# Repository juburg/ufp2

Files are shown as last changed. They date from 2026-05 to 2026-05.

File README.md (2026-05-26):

# UFP2 Firmware

Locked rebuild repository for the UFP-II firmware.

The current production build is:

```text
UFP2_V160/UFP2_V160.ino
```

The source was recovered from:

```text
C:\Users\juerg\Documents\_onedrive_kopie\Desktop\SW\UFP2_V160.ino
```

That file is the V1.60 production source from 2021-11-15. The code still reports
`SWversion = 1.51` on the display. This is preserved as-is because the goal here is
to rebuild the known production binary, not to polish the archaeology.

## Build

Use Arduino CLI:

```powershell
.\tools\build-ufp2.ps1
```

## Firmware Export

To create firmware files for external flashing:

```powershell
.\tools\export-ufp2-firmware.ps1 -SkipCoreInstall
```

If PowerShell script execution is blocked:

```cmd
tools\export-ufp2-firmware.bat -SkipCoreInstall
```

The exported files are written to `dist/UFP2_V160/` as `.bin`, `.hex`, and `.uf2`.
The `.uf2` file targets the Adafruit Feather M0/SAMD21 application start address
`0x2000` and can be copied to a Feather M0 UF2 bootloader drive if that bootloader
is installed.

The script installs and uses `adafruit:samd@1.7.17` in a workspace-local Arduino CLI
data directory and compiles only against the vendored third-party libraries in this
repository.

## Target

```text
Board: Adafruit Feather M0
FQBN:  adafruit:samd:adafruit_feather_m0:opt=small,usbstack=arduino,debug=off
```

## Mechanical Files

The latest UFP2 enclosure STL files are archived under:

```text
UFP_latest/UFP_latest/
```

## Historical Compiler Log

The original Arduino IDE 1.8.19 compiler log is archived at:

```text
docs/arduino-ide-1.8.19-build.log
```

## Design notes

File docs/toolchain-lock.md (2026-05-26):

# Toolchain Lock for UFP2

This repository contains the locked Arduino CLI rebuild path for UFP-II firmware:

```text
UFP2_V160/UFP2_V160.ino
```

## Pinned Build Inputs

- Board package: `adafruit:samd@1.7.17`
- Board package index: `https://adafruit.github.io/arduino-board-index/package_adafruit_index.json`
- FQBN: `adafruit:samd:adafruit_feather_m0:opt=small,usbstack=arduino,debug=off`
- Board: Adafruit Feather M0, SAMD21G18A / Cortex-M0+

The build script uses a workspace-local Arduino CLI data directory under:

```text
../.arduino-cli-ufp2
```

This prevents the compile from silently using libraries from the user's Arduino
sketchbook. Silence is nice in churches, less so in firmware builds.

## Vendored Arduino Libraries

The script builds only with these repository-local libraries:

```text
third_party/arduino-libraries/RadioHead-1.112
third_party/arduino-libraries/U8g2-2.31.2
third_party/arduino-libraries/DimmerZero-1.0.0
```

Core libraries are supplied by `adafruit:samd@1.7.17`:

```text
Wire 1.0
SPI 1.0
Adafruit_ZeroDMA 1.1.3
```

## Build Command

```powershell
.\tools\build-ufp2.ps1
```

## Firmware Export

```powershell
.\tools\export-ufp2-firmware.ps1 -SkipCoreInstall
```

The batch wrapper avoids PowerShell execution policy issues:

```cmd
tools\export-ufp2-firmware.bat -SkipCoreInstall
```

The export creates `dist/UFP2_V160/UFP2_V160.bin`,
`dist/UFP2_V160/UFP2_V160.hex`, and `dist/UFP2_V160/UFP2_V160.uf2`.
The UF2 file uses SAMD21 family ID `0x68ED2B88` and target address `0x2000`,
matching the Feather M0 linker script with the 8 KB bootloader region.

## Verified Output

Fresh local build with the repository-local Arduino CLI path:

```text
UFP2_V160 / V1.6.0:
Sketch uses 53008 bytes (20%) of program storage space. Maximum is 262144 bytes.
```

The archived Arduino IDE 1.8.19 compiler log reported 52984 bytes. The CLI build is
24 bytes larger, matching the same small delta seen on the related UFP2_RRC rebuild.

## Offline Boundary

The third-party Arduino libraries are vendored in this repository.
The Adafruit SAMD core and ARM toolchain are installed by Arduino CLI from the
Adafruit and Arduino package indexes when the script is run without
`-SkipCoreInstall`.

For a fully offline rebuild, archive the workspace-local
`../.arduino-cli-ufp2/data/packages` directory separately.

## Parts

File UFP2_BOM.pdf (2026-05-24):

Bill of Materials | UFP-II
Source Data From: | UFP2.PrjPcb
Project: | UFP2.PrjPcb
Variant: | None
Creation Date: | 12.10.2018 15:22:01
Print Date: | 03-Nov-18 3:59:32 PM
Coding & Comments | Quantity | Comment | Description | Designator
105 | 7 | 1uF | Capacitor THT 5.08 | C1, C2, C4, C6, C8, C10, C15
102 | 1 | 1nF 50V | Capacitor THT 5.08 | C3
473 | 3 | 47n 50V | Capacitor THT 5.08 | C5, C7, C9
334 | 3 | 330n | Capacitor THT 5.08 | C12, C13, C14
watch orientation! | 1 | 1N4148 | Diode, 200 mA, 100 V, 2-Pin DO-35 | D1
| 1 | Header 16 | Header, 16-Pin | JP1
| 1 | Header 12 | Header, 12-Pin | JP2
watch orientation! | 1 | SIL03-1A72-71D | RELAY REED SPST 0.5A 3V 500Ohm | K1
| 2 | Header 4x3 | Servo-Header | P1, P6
| 2 | Header 4 | Header, 4-Pin | P2, P3
| 1 | Header 3x3 | Servo-Header | P4
do not populate | 1 | JST_ZH_5 | Optional connector | P5
| 1 | Header 3X2 | Header, 3-Pin, Dual row | P7
watch orientation! | 2 | BC547BG | 'NPNTransistor , 3-Pin TO-92 | Q1, Q2
brown-black-green | 4 | 1M | Resistor 125mW 5% | R1, R8, R15, R21
yellow-violett-red | 1 | 4k7 | Resistor 125mW 5% | R2
brown-black-orange | 5 | 10k | Resistor 125mW 5% | R3, R5, R12, R17, R24
orange-orange-brown | 3 | 330R | 'Resistor 125mW 5% | R4, R6, R7
orange-orange-red | 3 | 3k3 | 'Resistor 125mW 5% | R18, R19, R26
brown-black-red | 10 | 1k | 'Resistor 125mW 5% | R9, R10, R11, R14, R16, R22, R23, R27, R28, R29
brown-black-yellow | 3 | 100k | 'Resistor 125mW 5% | R13, R20, R25
watch orientation! | 1 | KPM-G1240A | KPM-G1240A-K6390 Piezo sound generator | SG1
watch orientation! | 1 | LM339N | Quad Comparator, 14-pin MDIP | U1
| 58
Approved | | Notes
Altium Limited Confidential | 03.11.2018 | Page 1

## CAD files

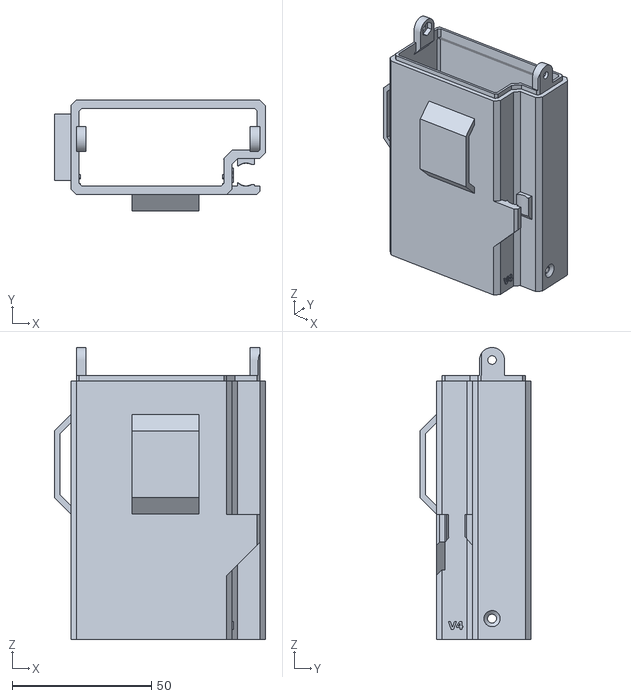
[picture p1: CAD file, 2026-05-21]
UFP_latest/UFP_latest/UFP2_2_V4_case_main.stl
75.9 x 39.9 x 105.0

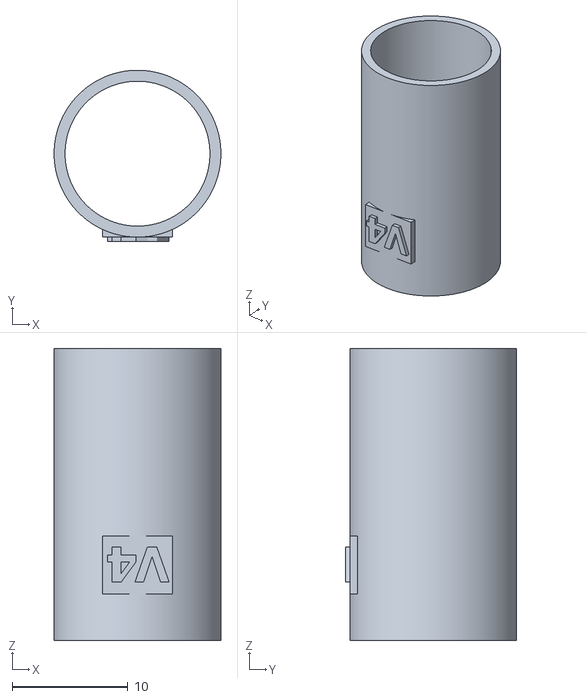
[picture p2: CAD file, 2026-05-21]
UFP_latest/UFP_latest/UFP2_5_V4_sound_tube.stl
14.4 x 14.8 x 25.2

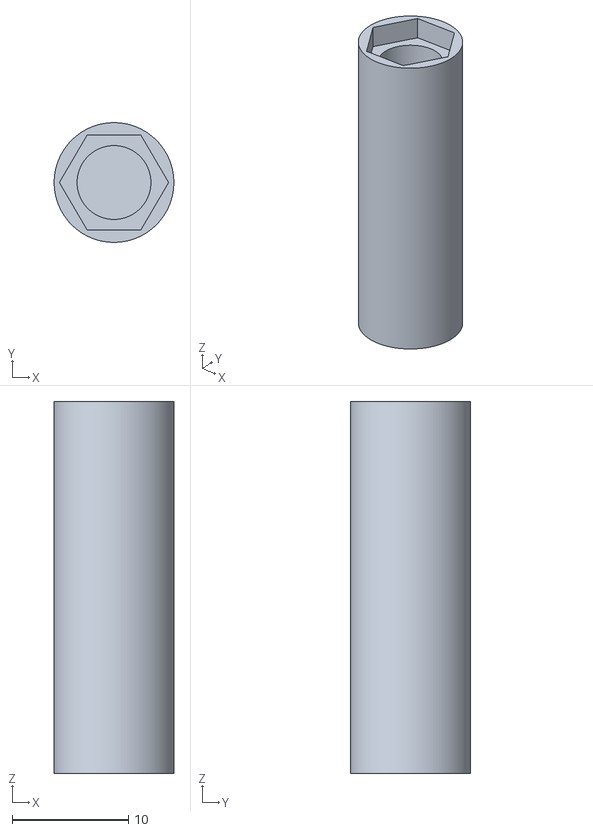
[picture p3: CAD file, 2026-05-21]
UFP_latest/UFP_latest/UFP2_antenna_tool_V4.stl
10.3 x 10.3 x 32.0

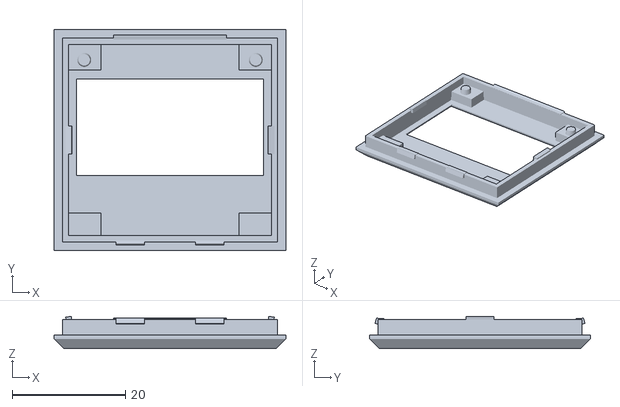
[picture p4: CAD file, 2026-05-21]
UFP_latest/UFP_latest/UFP2_6_V63_frame_LCD_var2.stl
40.9 x 38.9 x 5.73

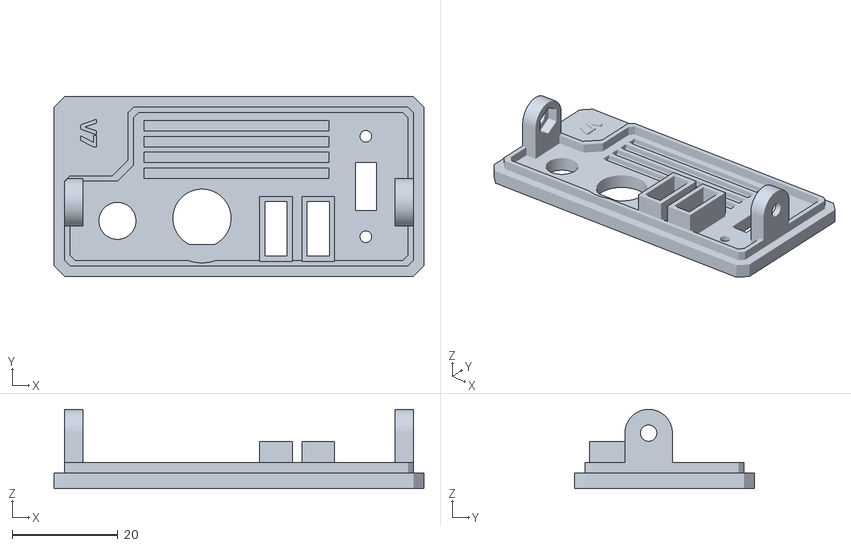
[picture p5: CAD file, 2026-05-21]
UFP_latest/UFP_latest/UFP2_1_V7_case_bottom.stl
70.0 x 34.0 x 15.0

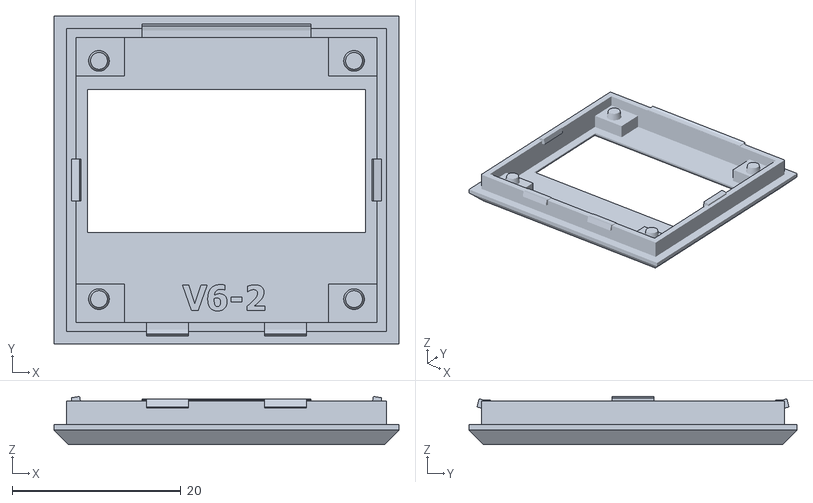
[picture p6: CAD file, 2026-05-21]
UFP_latest/UFP_latest/UFP2_6_V6_frame_LCD_var1.stl
40.9 x 38.9 x 5.73

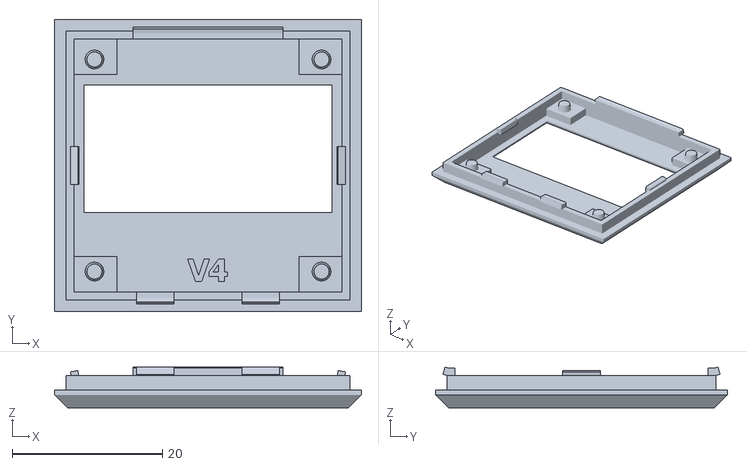
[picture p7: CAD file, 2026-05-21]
UFP_latest/UFP_latest/UFP2_4_V4_frame_LCD_orig.stl
40.9 x 38.9 x 5.44

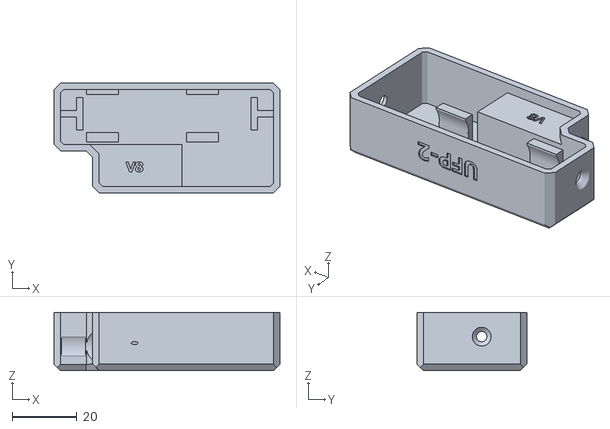
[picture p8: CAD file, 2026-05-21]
UFP_latest/UFP_latest/UFP2_3_V8_case_top.stl
70.0 x 34.0 x 18.0

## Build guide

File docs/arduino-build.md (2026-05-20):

# Arduino IDE Build Fingerprint

Archived log:

```text
docs/arduino-ide-1.8.19-build.log
```

Original sketch path in the log:

```text
C:\Users\juerg\Documents\Arduino\Sketches\UFP2_V160\UFP2_V160.ino
```

Recovered source path:

```text
C:\Users\juerg\Documents\_onedrive_kopie\Desktop\SW\UFP2_V160.ino
```

## IDE Inputs

- Arduino IDE: 1.8.19
- Board package: `adafruit:samd@1.7.17`
- FQBN: `adafruit:samd:adafruit_feather_m0:opt=small,usbstack=arduino,debug=off`
- Board: `adafruit_feather_m0`
- Core: `arduino`
- CPU: SAMD21G18A / Cortex-M0+
- Toolchain: `arm-none-eabi-gcc 9-2019q4`

## Libraries Resolved by the IDE Log

```text
Wire 1.0                         Adafruit SAMD core
SPI 1.0                          Adafruit SAMD core
Adafruit_ZeroDMA 1.1.3           Adafruit SAMD core
RadioHead-master 1.112           Arduino sketchbook
U8g2 2.31.2                      Arduino sketchbook
DimmerZero-master 1.0.0          Arduino sketchbook
```

## Original IDE Size

```text
Der Sketch verwendet 52984 Bytes (20%) des Programmspeicherplatzes. Das Maximum sind 262144 Bytes.
```

## Known Oddity

`UFP2_V160.ino` contains a V1.60 release-history entry for 2021-11-15, but the source
still defines:

```cpp
const float SWversion = 1.51;
```

That mismatch is intentionally preserved. A build lock is not a beautician.

The recovered V1.60 source also contained `-1` sentinel values inside a `byte`
lookup table. The historical V1.51 source used `255` for the same table, which is
the actual byte value produced by `-1`. The repository source uses `255` so modern
Arduino CLI can compile it without C++ narrowing errors.

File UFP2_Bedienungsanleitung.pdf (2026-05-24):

Universeller Funk-Piepser II

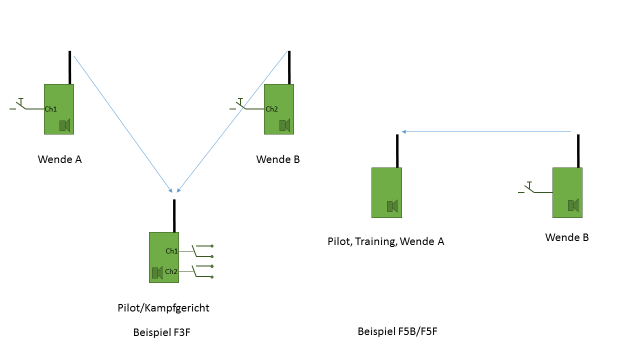
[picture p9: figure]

fcd@gmx.org | 1
1 | Einführung

Der Universelle Funk-Piepser (UFP-II) ersetzt bei Fxx-Training und Wettbewerben die sonst übliche Kabelverbindung zwischen den Wenden und dem Pilotenstandort bzw. dem Wettbewerbssystem zum Übertragen des Wendesignals. Für das Training ist ein kleiner Signalgeber direkt integriert, für Wettbewerbseinsatz stehen bis zu drei Ausgangs-Signale (3V) und ein potentialfreier Kontakt zur Signalisierung zur Verfügung. Die zu überbrückende Entfernung beträgt unter realistischen Bedingungen und Montage in > 1.5m Höhe 300m (line of sight), unter idealen Bedingungen bis zu 600m. Für extreme Anwendungen kann die Reichweite mittels spezieller Antennen mit etwa 3dBi Gewinn anstelle der Drahtantenne oder der optional mitgelieferten λ/4-Rundstrahlantennen verdoppelt werden¹

Ein UFP-II-System besteht minimal aus zwei Geräten, einer als Sender (TX) und einer als Empfänger (RX) konfigurierten Einheit. Die Empfangseinheit kann auf bis zu drei Sendeeinheiten hören, von der jede drei unterscheidbare Signalisierungskanäle besitzt. Wird das Wendesignal an den Sendeeinheiten auf die drei möglichen Signalisierungskanäle verteilt, kann die Empfangseinheit jede dieser Signale getrennt melden.

Beispiel-Topologie für F3F, zwei Wenderichter mit Sender (TX) A und (TX) B, ein Empfänger (RX); Wende A belegt Kanal 1, Wende B Kanal 2. Am Empfangsort stehen wieder beide Kanäle als potentialfreie Kontakte zur Verfügung. Das akustische Signal wird für beide Wenden gemeinsam verwendet. Das Beispiel F5B/F für den Trainingsbetrieb kommt mit nur zwei Geräten aus.

Stehen für F5B/F-Training Wenderichter an der B-Wende und auch an der A-Wende zur Verfügung, kann an dem als Receiver (RX) konfigurierten UFP-II an der A-Wende neben einem Drücker für die Durchflugsignalisierung auch ein Kontrollempfänger und ein Taster für den Rundenstart angeschlossen werden, um Motoreinflüge zu signalisieren und um die geflogenen Strecken wettkampfkonform zu zählen. Ein optional anschließbares OLED Display gibt dann den zugehörigen Status und die geflogenen Strecken aus.

1
Landesspezifische Vorschriften beachten!

2 | Parametrierung
| Achtung: bei allen Arbeiten an den Boards unbedingt ESD-Vorschriften beachten!
| Sende- und Empfangseinheit unterscheiden sich nur durch Parametrierung, was mittels Jumper erfolgt. Die
Abb. 1 zeigt unter anderem die Lage der Jumper (Feld P7) auf dem Gerät.

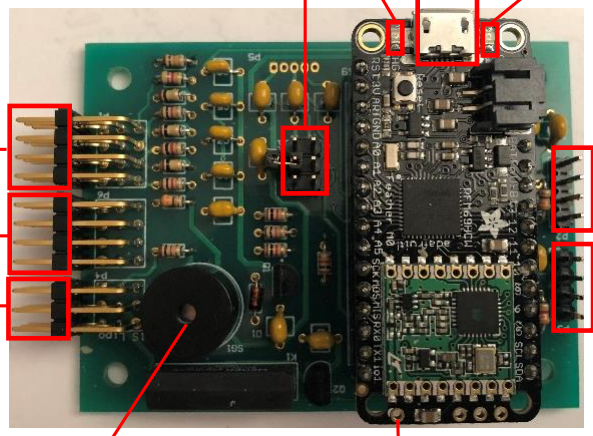
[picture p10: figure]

Abb. 1 Lage der Anschluss- und Jumper-Felder

Die 3 möglichen Betriebsarten-Jumper (P7, Abb. 1) dienen zur Einstellung der Basis-Betriebsart (TX oder RX) und zum Aktivieren von kurzen Signalen nach Motor-EIN (nur bei betrieb mit Kontrollempfänger) als Trainingshinweis zum Abstellen des Motors.

Es sind insgesamt 3 Betriebsarten mit den ersten 2 Jumper-Positionen des Feldes P7 definiert:

Mode | TX | RX | RX-M
Jumper-Anordnung

Dabei bedeuten:

Mode TX: | Sendebetrieb (TX)
Mode RX: | Empfangsbetrieb (RX)

Mode RX-M: Empfangsbetrieb (RX), mit Motor-AUS-Hinweis (Kontrollempfänger erforderlich)

Andere Jumperanordnungen sind reserviert für zukünftige Erweiterungen und dürfen nicht verwendet werden!

P3

P7

P1

P6

P4

Antennen-Anschluss (Drahtantenne) (u.FL-Buchse auf Unterseite des Moduls)

P2

Micro-USB

Signalgeber

LED rot

LED gelb

3 | Belegung der Pin-Header (‚Servo-Anschluss‘)
| Die Anschlussfelder P1, P4 und P6 (vgl. Abb. 1) sind mit Pin-Headern bestückt, auf die handelsübliche Servo- Stecker passen. Anschlussfeld P1 dient der Einspeisung von Wendesignalen, an Feld P6 werden die Wendesignale zur Ausgabe bereitgestellt (hier wird normalerweise nichts angeschlossen) und Feld P4 dient dem Anschluss von Batterie, Einschalter und ev. externer LED zur Signalisierung des Betriebszustandes (On/Off). Die drei übereinander liegenden Pins sind mit 1, 2 und 3 bezeichnet, Pin 1 dicht an der Leiterplatte.
| Belegungstabelle bei Konfiguration als Sender (TX), von oben:
| P1, Kanal 1: Wendesignal, Ch1‘, für Anschluss FCD, pin1 GND, pin 2 Ubatt, pin3 Wendesignal
| (hierüber kann UFP-II auch von FCD mit Energie versorgt werden; keine getrennte Batterie erforderlich!)
| P1, Kanal 2: Wendesignal Ch1, Binär/Taste); Binär pin1 GND, pin 2 3V3, pin3 Signal; Taste an pin2/3
| P1, Kanal 3: Wendesignal Ch2, Binär/Taste); Binär pin1 GND, pin 2 3V3, pin3 Signal; Taste an pin2/3
| P1, Kanal 4: Wendesignal Ch3, Binär/Taste); Binär pin1 GND, pin 2 3V3, pin3 Signal; Taste an pin2/3
| Wird Kanal 4 dauerhaft überbrückt (z.B. Jumper), erfolgt nach 5s ein zyklisches Senden (Zykluszeit 1s) zur Reichweitenüberprüfung.
| P4, Kanal 1: LED, Ext. LED² Kathode (-) an pin 1, Anode an pin 2;
| P4, Kanal 2: PWR, Batterie/Akku (max. 5V), – an pin1, + an pin 2
| P4, Kanal 3: PWR, Einschalter über pin2 und pin 3;
| alternativ Batterie/Akku an pin1 (-) und pin 2 (+), wenn EIN-Schalter in Akku-Zuleitung

Belegungstabelle bei Konfiguration als Empfänger (RX), von oben:

P1, Kanal 1: Eingang, Anschluß Kontrollempfänger, GND an pin 1

P1, Kanal 2: Wendesignal A-Wende, Binär/Taste; Binär pin1 GND, pin 2 3V3, pin3 Signal; Taste an pin2/3

P1, Kanal 3: keine Funktion

P1, Kanal 4: Startfreigabe, Binär/Taste; Binär pin1 GND, pin 2 3V3, pin3 Signal; Taste an pin2/3

P6, Kanal 1: OUT, Wendesignal Ch1 oder Ch1‘; Signal an pin 3, GND an pin 1

P6, Kanal 2: OUT, Wendesignal Ch2; Signal an pin 3, GND an pin 1

P6, Kanal 3: OUT, Wendesignal Ch3; Signal an pin 3, GND an pin 1

P6, Kanal 4: OUT, Wendesignal CH1’, CH1, CH2, CH3 verodert; Relais-Kontakte an pin 2 und pin 3

P4, Kanal 1: LED, Ext. LED³ Kathode (-) an pin 1, Anode an pin 2;

P4, Kanal 2: PWR, Batterie/Akku (max. 5V), – an pin1, + an pin 2

P4, Kanal 3: PWR, Einschalter über pin2 und pin 3;

alternativ Batterie/Akku an pin1 (-) und pin 2 (+), wenn EIN-Schalter in Akku-Zuleitung

2
LED-Strom 0.3mA, daher nur LED mit 2mA für volle Helligkeit verwenden
3
LED-Strom 0.3mA, daher nur LED mit 2mA für volle Helligkeit verwenden

4 | Pinheader P2 und P3
| Die beiden 4-poligen Pinheader P2 und P3 sind für Optionen vorgesehen. P2 ermöglicht eine serielle Kommunikation via UART, ist derzeit noch ohne freigegebene Funktion.
| Header P3 implementiert eine I2C-Schnittstelle und dient dem Anschluss eines optionalen OLED Displays.
| Pinbelegung P3 (I2C-Interface):
| P3, pin 1: SCL oder SCK
| P3, pin 2: SDA
| P3, pin 3: +3.3V
| P3, pin 4: GND
| Achtung: die Pin-Reihenfolge kann auf den OLED-Displays je nach Hersteller unterschiedlich sein! Vor Anschluss sehr genau prüfen!
5 | Antennenanschluss
| Sende- und Empfangseinheit benötigen eine externe Antenne zum Erreichen der angegebenen Reichweite. Dazu ist eine Drahtantenne von 86mm Länge an die in Abb. 2 gekennzeichnete Bohrung des Prozessor- Boards einzulöten,

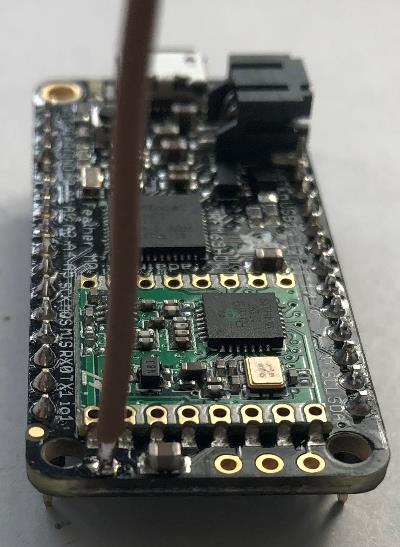
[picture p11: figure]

Abb. 2 Eingelötete Drahtantenne

oder die optional mitgelieferte SMA-Antenne mit Antennenkabel, abgestimmt auf das 868MHz-Band, mit ihrem u.fl Micro-Coax-Stecke auf der Unterseite des Prozessor-Boards vorsichtig anzustecken (Abb. 3-5).

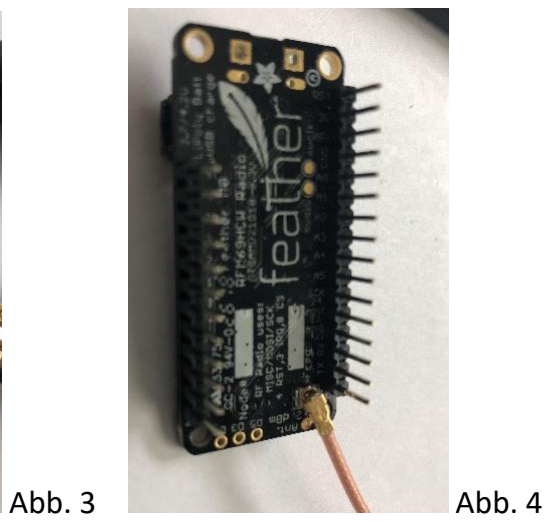
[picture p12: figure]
Abb. 3; Abb. 4
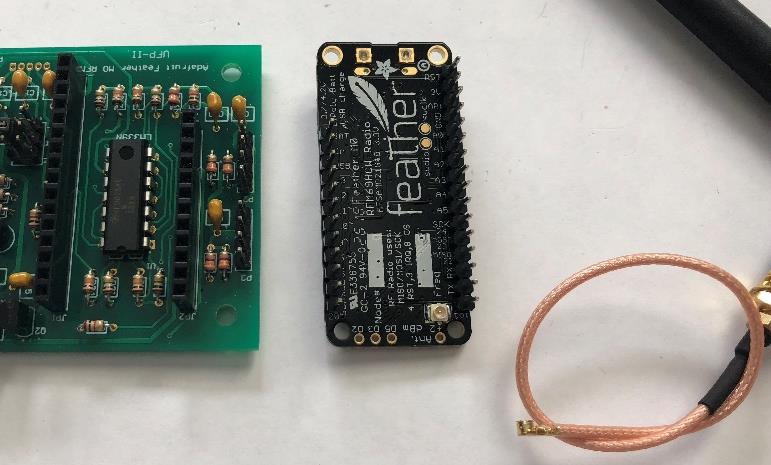
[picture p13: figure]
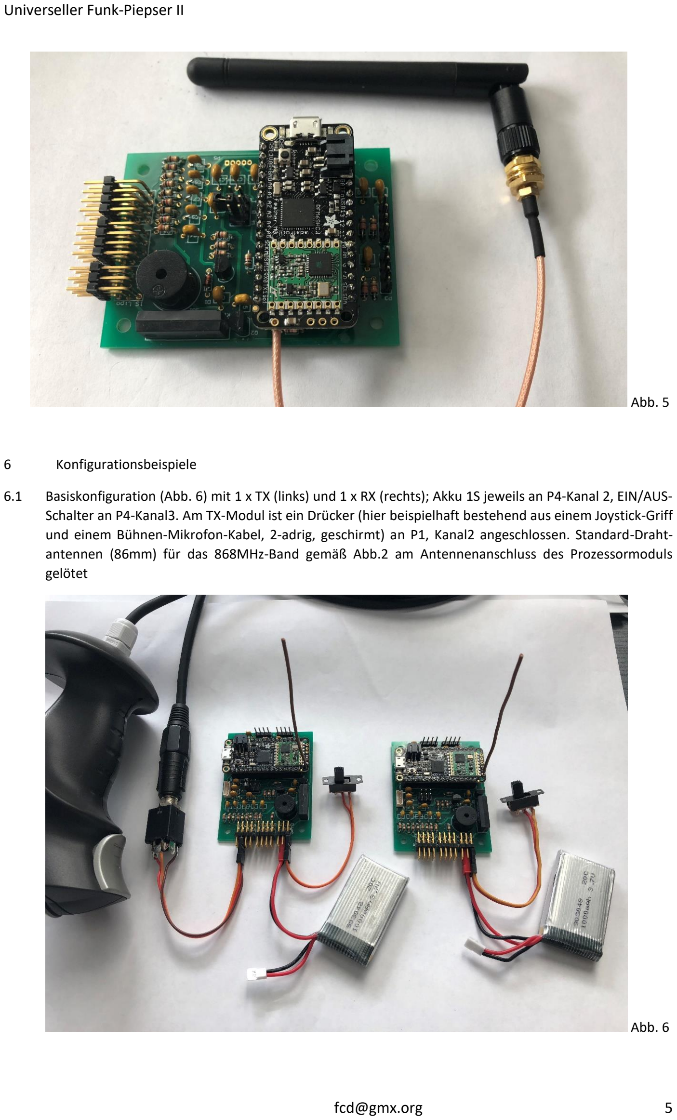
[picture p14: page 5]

Abb. 5

6 | Konfigurationsbeispiele
6.1 | Basiskonfiguration (Abb. 6) mit 1 x TX (links) und 1 x RX (rechts); Akku 1S jeweils an P4-Kanal 2, EIN/AUS- Schalter an P4-Kanal3. Am TX-Modul ist ein Drücker (hier beispielhaft bestehend aus einem Joystick-Griff und einem Bühnen-Mikrofon-Kabel, 2-adrig, geschirmt) an P1, Kanal2 angeschlossen. Standard-Draht- antennen (86mm) für das 868MHz-Band gemäß Abb.2 am Antennenanschluss des Prozessormoduls gelötet

Abb. 6

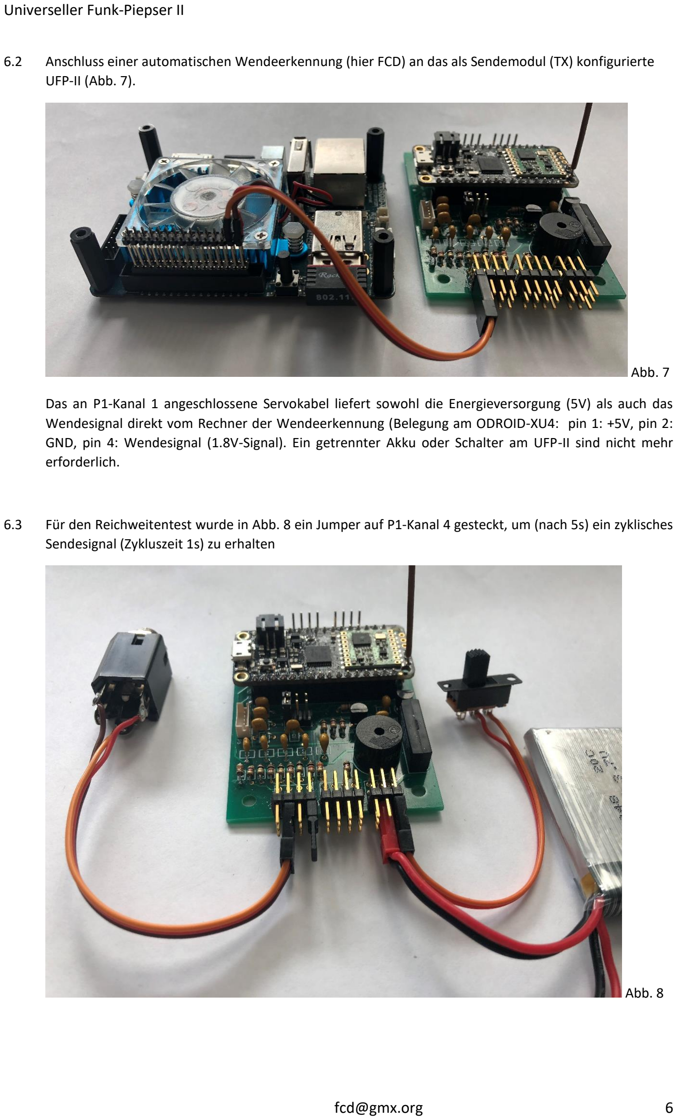
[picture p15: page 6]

6.2 Anschluss einer automatischen Wendeerkennung (hier FCD) an das als Sendemodul (TX) konfigurierte UFP-II (Abb. 7).

Abb. 7

Das an P1-Kanal 1 angeschlossene Servokabel liefert sowohl die Energieversorgung (5V) als auch das Wendesignal direkt vom Rechner der Wendeerkennung (Belegung am ODROID-XU4: pin 1: +5V, pin 2: GND, pin 4: Wendesignal (1.8V-Signal). Ein getrennter Akku oder Schalter am UFP-II sind nicht mehr erforderlich.

6.3 Für den Reichweitentest wurde in Abb. 8 ein Jumper auf P1-Kanal 4 gesteckt, um (nach 5s) ein zyklisches Sendesignal (Zykluszeit 1s) zu erhalten

Abb. 8

6.4 Wer eine externe Betriebsanzeige benötigt, kann eine LED direkt an P4-Kanal 1, pin 1- und 2+ anschließen (Abb. 9). Ein Vorwiderstand 1k ist bereits eingebaut. Es sollten nur LED verwendet werden, die schon bei 2mA ihre Nennintensität erreichen.

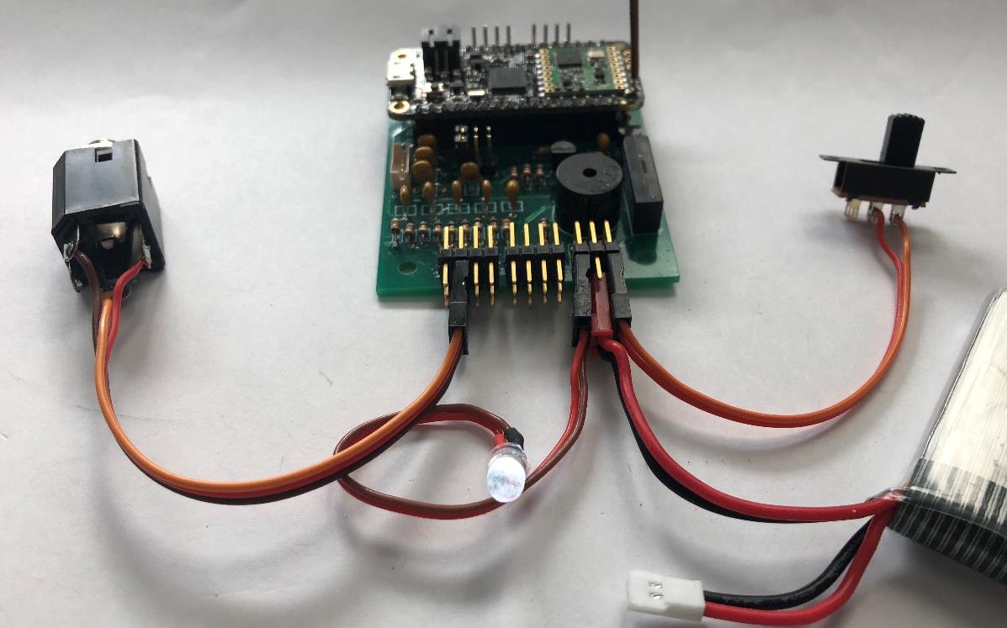
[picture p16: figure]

Abb. 9

6.5 Steht ein Wenderichter für die A-Wende zur Verfügung, macht es Sinn einen Kontrollempfänger anzuschließen, um auch auf Motoreinflüge zu überwachen. Abb. 10 zeigt die erforderliche Konfiguration.

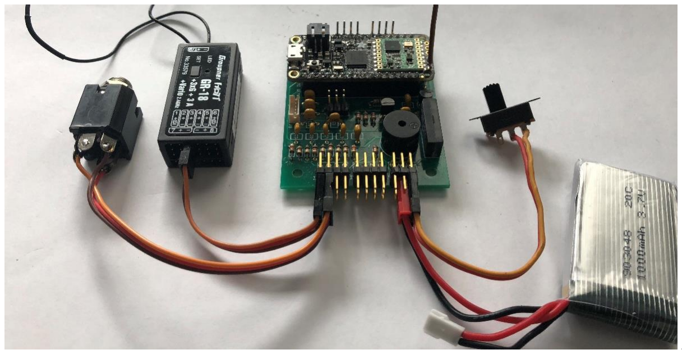
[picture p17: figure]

Abb. 10

Der Kontrollempfänger kommt an P1-Kanal 1, der Drücker für die A-Wende an P1-Kanal 2. Am Kontrollempfänger ist natürlich der Motor-Kanal zu verwenden. Bei Motoreinflug wird statt des normalen Wendesignals ein tieferer Ton ausgegeben.

6.6 Wer möchte, kann das System noch mit einem OLED Display aufwerten (siehe Abb. 11). Beim Einschalten wird die Softwareversion und die Übertragungsfrequenz sowie Sendeleistung angezeigt. Nach 4s erscheint die Anzeige wie in Abb. 11. Nutzbar sind hier nur die Anzeige des Motorsignals (hier 1452µs) und das daraus abgeleitete Motor-EIN/AUS-Signal (hier On für EIN).

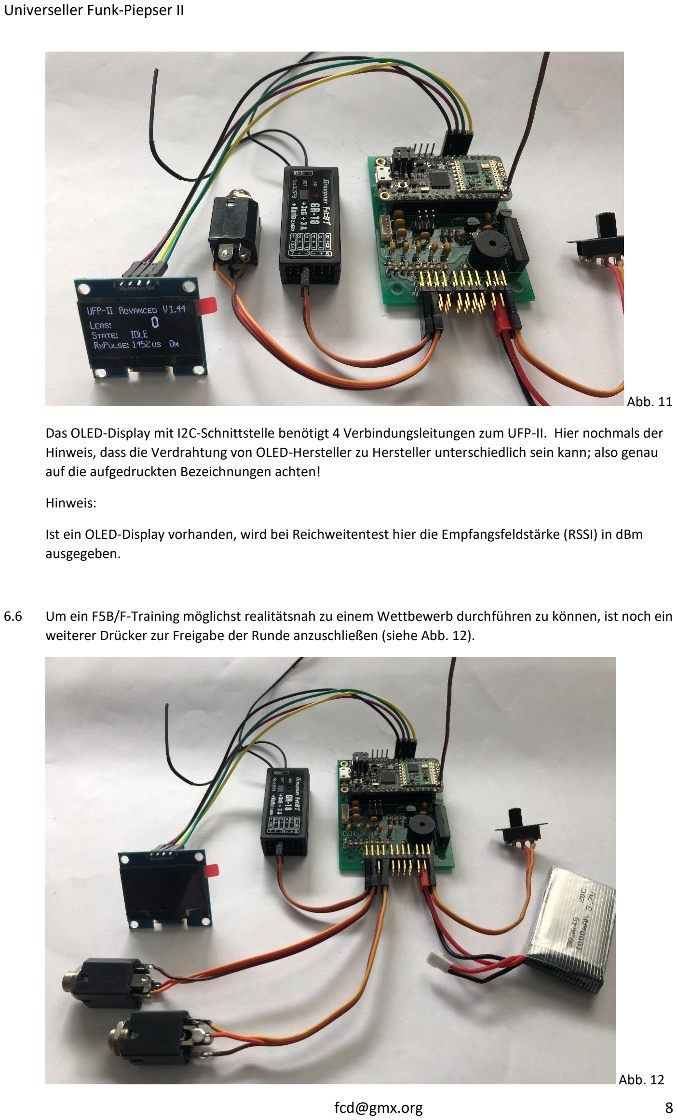
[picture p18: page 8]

Abb. 11

Das OLED-Display mit I2C-Schnittstelle benötigt 4 Verbindungsleitungen zum UFP-II. Hier nochmals der Hinweis, dass die Verdrahtung von OLED-Hersteller zu Hersteller unterschiedlich sein kann; also genau auf die aufgedruckten Bezeichnungen achten!

Hinweis:

Ist ein OLED-Display vorhanden, wird bei Reichweitentest hier die Empfangsfeldstärke (RSSI) in dBm ausgegeben.

6.6 Um ein F5B/F-Training möglichst realitätsnah zu einem Wettbewerb durchführen zu können, ist noch ein weiterer Drücker zur Freigabe der Runde anzuschließen (siehe Abb. 12).

Abb. 12

Der Drücker zur Rundenfreigabe kommt an P1-Kanal 4. Bei eingeschaltetem Sender sollte der Motor als Off (AUS) angezeigt werden (in Abb. 13 Pulsweite 1241µs, Motor Off). Die Runde ist noch nicht freigegeben (State: IDLE). Nach Betätigen des Drückers zur Rundenfreigabe wird Startbereitschaft angezeigt (State: START, Abb. 14). Die eigentliche Rundenzählung und Motoreinflugüberwachung beginnt automatisch mit dem nächsten Motor-Einschalten (der kleine Fehler zum echten Wettbewerb mit Rundenbeginn bei Verlassen des Modells aus der Hand des Starthelfers) dürfte zu verschmerzen sein und spart einen weiteren Helfer. Mit dem ersten Motor-EIN-Signal ist die Runde gestartet (State: RUN) und die 200s der Streckenaufgabe wird heruntergezählt. Nach dem ersten A-Signal (Einflug in Strecke) ist auch die Motoreinflugüberwachung (*) scharf. In Abb. 15 ist bereits das erste Wendesignal von der B-Wende gekommen, das Modell hat die A-Wende noch nicht wieder erreicht (Legs: 1, *, RUN, verbleibende Streckenzeit (178,2s). Mit Abschluss der Streckenzeit (hoher Signalton) wird wieder der IDLE-Status erreicht, die erreichte Streckenzahl bleibt aber weiterhin bis zur nächsten Freigabe angezeigt.

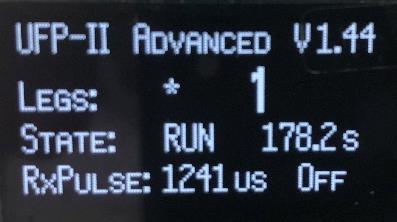
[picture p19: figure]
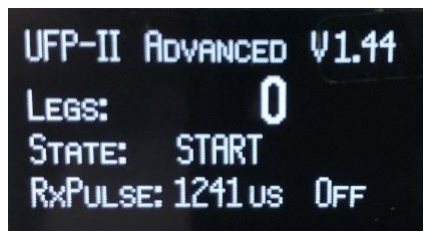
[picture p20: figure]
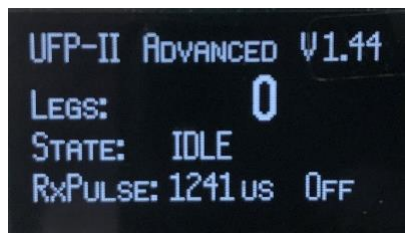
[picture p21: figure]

Abb 13 | Abb. 14 | Abb. 15

Wird ein Flug abgebrochen, wird durch eine Erneute Rundenfreigabe die laufende Runde beendet und wieder Startbereitschaft (Abb. 14) signalisiert.

7 | LED-Anzeigen
| Auf dem Prozessorboard befinden sich 2 LEDs zur Anzeige des Betriebszustandes:
- LED rot
| Laufanzeige des Programms; Dauerlicht für 6s während des Starts, danach kurzes Aufblitzen im Sekundentakt
- LED gelb
| Ladeanzeige des Akkus (siehe Abschnitt 8)
8 | Akku-Ladefunktion
| Zum Aufladen des angeschlossenen und eingeschalteten Akkus (1S LiPo) kann der Micro-USB- Anschluss des Prozessorboards verwendet werden: wird er von einem PC oder Powerpack versorgt, wird der Akku mit 100mA auf 4.2V aufgeladen. Während des Ladevorgangs leuchtet eine gelbe LED auf.

9 | Technische Daten:
- Temperaturbereich Betrieb: -15°C bis +55°C
- Realistische Reichweite mit Drahtantenne 300m (erweiterbar mit Spezial- Antennen)
- Stromaufnahme RX typisch 17mA/50mA (max. Wert bei Signalübertragung)
- Stromaufnahme TX typisch 25mA/100mA (max. Wert bei Signalübertragung)
- Latenzzeit typisch 6ms, mit Relais 6.5ms; im Ausnahmefall bei hoher Senderdichte 9ms
- Signalisierung mittels Piezo-Piepser, 3 Töne (ca. 86dBA);
- Schaltschwelle Binärsignal: 1.25V, Eingangsimpedanz 10k, max. 5V
- Tastenstrom bei Betätigung 3V/1mA
- Antenne Draht oder Lamda/4, Stecksystem: u.fl micro-coax
- Betriebsspannung 3.3VDC bis 5.0DC, effizient 3.6V bis 5V (1S-Lipo, USB)
- Übertragungsfrequenz 868MHz-Band
- Sendeleistung (25/50mW je nach Frequenz)
- Potentialfreier Kontakt 125V/500mA

10 Anhang
Pinout des verwendeten Prozessorboards Adafruit Feather M0 RFM69HCW (von der Adafruit Web-Seite): https://learn.adafruit.com/assets/46254

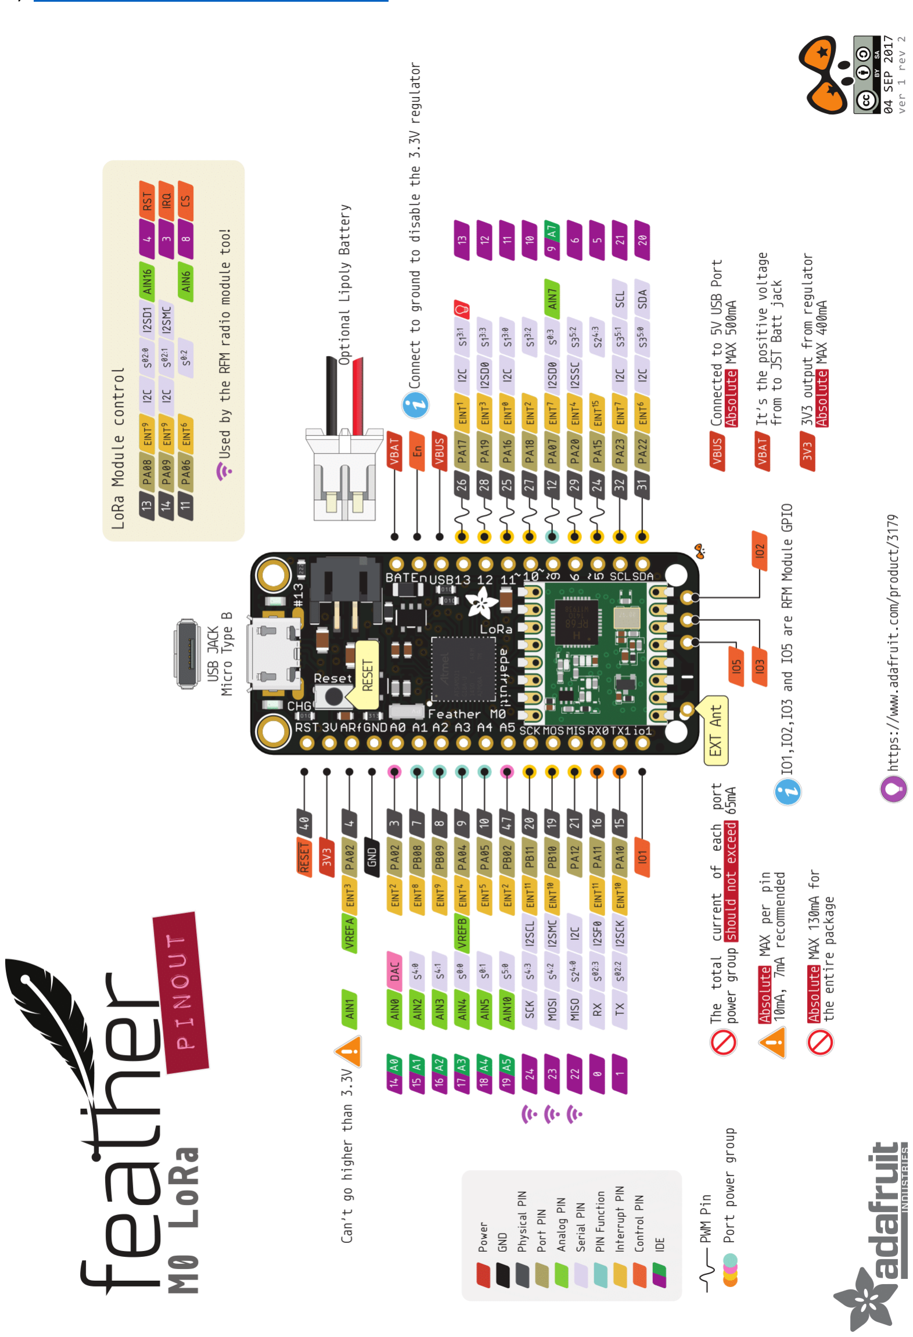
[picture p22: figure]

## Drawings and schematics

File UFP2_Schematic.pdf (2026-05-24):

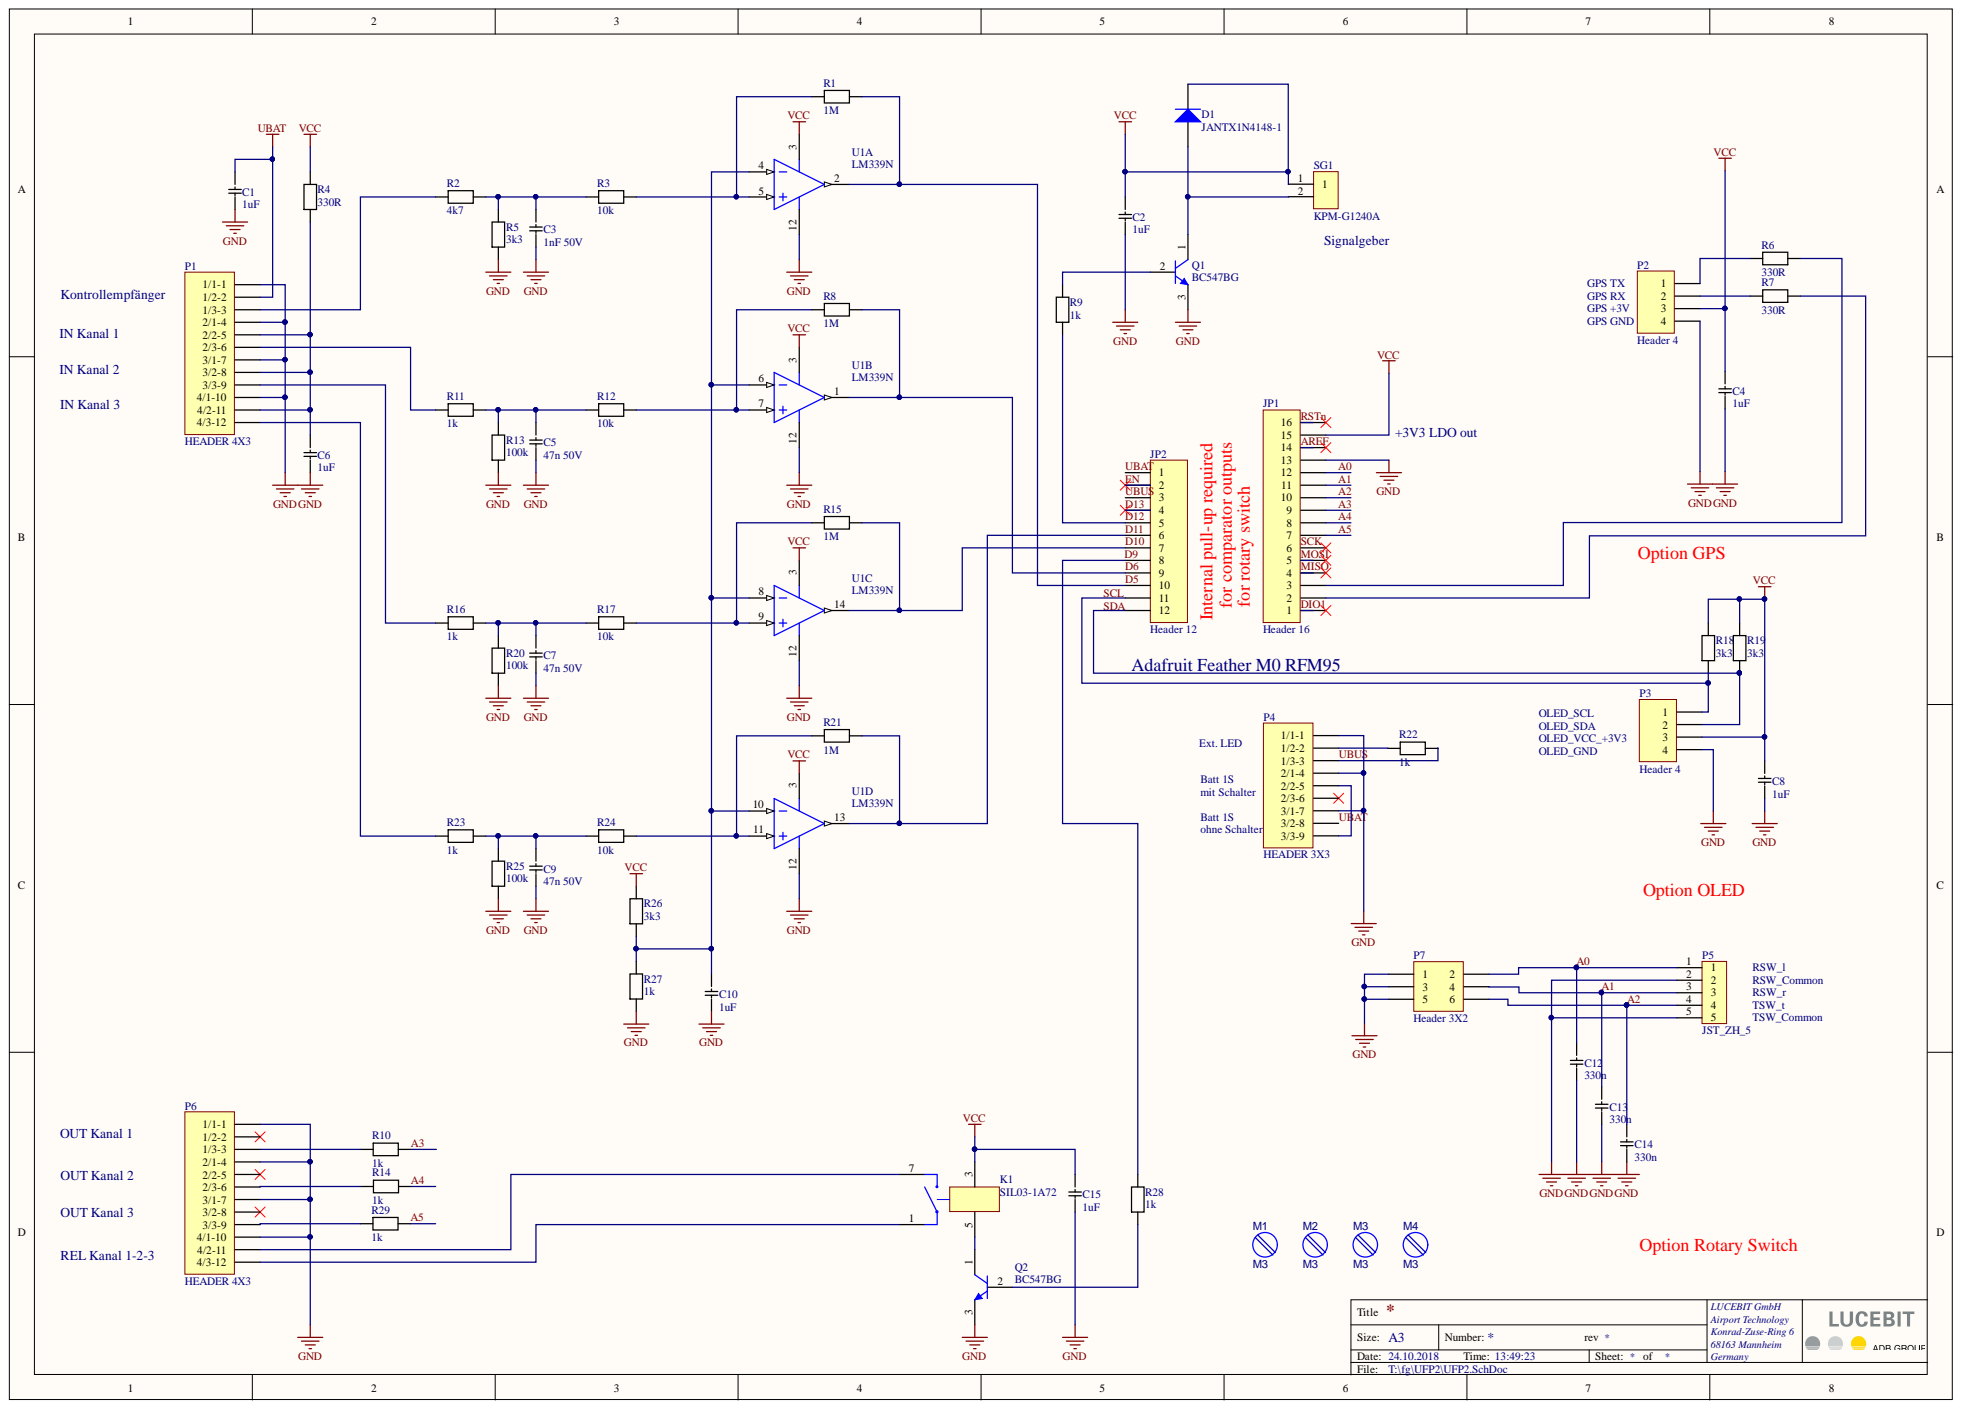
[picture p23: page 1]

Internal pull-up required

D5
SCL

VCC | U1D LM339N

UBUS

* Title | LUCEBIT GmbH Airport Technology Konrad-Zuse-Ring 6 68163 Mannheim Germany

Size: A3 | Number: * rev *
Date: 24.10.2018 Time: 13:49:23 | Sheet: * of *

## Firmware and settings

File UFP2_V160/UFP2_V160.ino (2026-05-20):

// -*- mode: C++ -*-
//
// UFP-II
//
// Software designed for *Adafruit Feather M0 RFM69HCM* module
//
// 
// Release history:
//
// V1.60 20211115 serial export of start/beep events
//                (RUN:'C', START: 'B', IDLE: 'A',  A-Beep: 'D', B-Beep: 'E', EngineAlert (B->A): 'F',
//                EngineAlert at A-turn enroute (B-> A): 'G', EngineAlert at enroute (A-> B): 'H', End of Speed: '@', legs: 0..63 (0x3F))
// V1.51 20190709 feature: cyclic beep (2s)in TX mode for range tests (CH3IN active during boot);
//                in RX range test off when normal message received
// V1.50 20181231 bug fix: range test request re-implementetd (lost in V1.46)
//                feature: jumper (M) when modified hw for batt measurement used (D9 routed to D1, measurement activated)
//                feature: background display update (1/s) when no crossing signal present, else update after beep
//                feature: no I2C communication to display when display not present (checked during setup)
// V1.48 20181213 Relais driver control  moved from D9 to D1 (TX); D9 aka A7 measures the battery voltage
//                Hardware modification required (disconnect R28 from JP2-8 and reconnect to JP1-2 (TX));
//                SPI-pins used by radio!
// V1.47 20181211 handleRaceEvents (former handleRace) optimized
// V1.46 20181209 GPS support removed
// V1.45 20181103 bug fix in round trip end beep
// V1.44 20181027 bug fixes in GPS interface, base to rover transmission speed improved
// V1.43 20181027 bug fixes in GPS interface, parser speed improved
// V1.42 20181026 bug fixes in GPS interface, parser
// V1.41 20181025 bug fixes in contest engine
// V1.4 20181024  support for GPS RTK Base and Rover for GPS module SkyTra S1216F8-RTK (parser for NMEA PSTI-032 protocol)
// V1.3 20181023  faster update of OLED implemented
// V1.2 20181020  support for GPS RTK Base and Rover (data link) & GPS based distance calculation of base line; accuracy +/-1.25cm
//                Required GPS module: ublox NEO-M8P-2
// V1.1 20181002  support for supply via FCD in TX modes
// V1.0 20180925  Initial design, incl. control receiver interface, OLED display interface, and Start/Reset key input in RX modes (no FRAM, no rotary key).
//                Beep frequencies and durations fixed.
// 
// 0-3 jumpers on P7 define the operational mode as follows:
//
// 5-6  Voltage Measurement:   closed: active         open: off
// 3-4  Engine off beep:       closed: active,        open: off
// 1-2  OperationMode:         closed: TX,            open: RX
//
// All messages sent and received by the RH_RF69 driver conform to this packet format:
//
// - 4 octets PREAMBLE
// - 2 octets SYNC 0x2a, 0x54 (configurable, so you can use this as a network filter to destinguish from other UFP-II)
// - 1 octet RH_RF69 payload length
// - 4 octets HEADER: (TO, FROM, ID, FLAGS)
// - 0 to 60 octets DATA 
// - 2 octets CRC computed with CRC16(IBM), computed on HEADER and DATA
//
//  With currently 2 byte payload (message number and crossing status), 15 bytes or 120 bits will be transmitted in a message.
//  Selecting GFSK with 55kBit/s, the on air time is about 2ms, the time from crossing event at the transmitter to status
//  change at the receiver will sum up to about 6ms. The message is resent once after a brief delay of 2ms for increased reliability.
//  On the receiver side, this resent message is ignored when the original message was received successfully.
//
//  Allowed ISM frequencies in Germany according to vfg5/2018:
//  "Allgemeinzuteilung von Frequenzen zur Nutzung durch Funkanwendungen mit geringer Reichweite für nicht näher spezifizierte Anwendungen;
//  Non-specific Short Range Devices (SRD)"
//
//    (1) 433,050 MHz - 434,790 MHz @ 10mW (0dBm)
//    (2) 865,0 MHz - 868,0 MHz @ 25mW (14dBm), on air duty cycle max. 1% (radio band typically used for radio mices and 2W RFID)
//    (3) 868,0 MHz - 868,6 MHz @ 25mW (14dBm), on air duty cycle max. 1%
//    (4) 868,7 MHz - 869,2 MHz @ 25mW (14dBm), on air duty cycle max. 0.1%
//    (5) 869,40 MHz - 869,65 MHz @ 500mW (27dBm), on air duty cycle max. 10%
//    (6) 869,7 MHz – 870,0 MHz @ 25mW (14dBm), on air duty cycle max. 1%
//
//  The duty cycle is defined as "at any time within an hour", i.e. a 0.1% duty cycle allows for 3.6s on air time in the hour. This gives 
//  up to 1800 transmissions or at least 15 flight blocks the hour (up to 60 legs, double clicked: 120ms); thats nearly impossible; so no
//  problem to use any of the frequency bands above, even the most sensitive (4). This gives up 22 possible channels with a bandwidth of 200kHz
//
//  Proposed frequency for 433MHz band: 434,685 MHz
//
//  Proposed frequency for 868MHz band: 869.525 MHz
//
//  
//  Engine shutoff command beep:
//    Requirements:   reference receiver connected to RX port (P1-1, pin 1,2,3)
//    Purpose:        F5B/F training hint to shut off the engine during climb at A Base
//    Implementation: when the engine is on for more then 1.35s (climb for 4 legs), a 200ms beep at 3000Hz is emitted
//                    when the engine is on for more then 2.25s (climb for 6 legs or 4 legs F5F), a 200ms beep at 3500Hz is emitted
//    Default engine ON detection: RX pulse duration > 1350us
//


/********* Includes *********/
#include <Wire.h>
#include <SPI.h>
#include <RH_RF69.h>
#include <U8g2lib.h>
#include <avr/dtostrf.h>
//#include <Adafruit_FRAM_I2C.h>
#include <DimmerZero.h>
// Attention: DimmerZero library had been modified

// Defines


// OLED interface (depending on controller chip)
#define SH1106_F
//#define SH1306_F
#define  OLED_ADDR  0x3C

// Debug
//#define debug
//#define debug1

/************ Radio Setup ***************/
// set frequency for receiver and transmitter
// 433MHz band: channel 1..8  (transceiver with red dot)
// 868MHz band: channel 9..30 (transceiver with green dot)
// 915MHz band:

#define TXPWRHH 20
#define TXPWRH 17
#define TXPWRL 14

// I/Os for the radio modue RFM69HCM on M0
#define RFM69_CS      8
#define RFM69_INT     3
#define RFM69_RST     4

#define RH_RF69_MESSAGE_LEN   2

/****** engine off beep duration ********/
#define CLIMB4LEGTIME 1350
#define CLIMB6LEGTIME 2250

/*** duration of message bits active ****/
#define SIGNALTIME  400

/*** duration of beep tones *************/
#define BEEPTIME    400
#define MBEEPTIME   250
#define EBEEPTIME   200
#define RTEEPTIME   1500

/***** Timer setup **********************/
// ARM core operates at 48MHz
#define CPU_HZ 48000000
#define TIMER_PRESCALER_DIV 1024
#define TICK_COUNTS_1S 1000

/***** I/O definitions ******************/
#define LED           13
#define CTRLRECEIVER  5
#define CH1IN         6
#define CH2IN         10
#define CH3IN         11
#define RELAIS        9
#define RELAISMOD     1 /* TX */
#define CH1OUT        A3
#define CH2OUT        A4
#define CH3OUT        A5
#define BEEPER        12
#define KEYL          A0
#define KEYR          A1
#define KEYT          A2
#define SCL           21
#define SDA           20

#define BUFLEN  3000

// start sequence defines
#define IDLE  0
#define START 1
#define RUN   2

// engine defines
#define ON    2
#define OFF   1
#define INV   0

// leg update define
#define A_TURN  0
#define B_TURN  1






// Instance of the radio driver
RH_RF69 rf69(RFM69_CS, RFM69_INT);

// Instance of the OLED driver
// default address 0x3C
#ifdef SH1106_P
  U8G2_SH1106_128X64_NONAME_2_HW_I2C u8g2(U8G2_R0); // Page buffer mode
#endif
#ifdef SH1106_F
  U8G2_SH1106_128X64_NONAME_F_HW_I2C u8g2(U8G2_R0); // Full screen buffer mode
#endif
#ifdef SH1306_P
  U8G2_SSD1306_128X64_NONAME_2_HW_I2C u8g2(U8G2_R0);
#endif
#ifdef SH1306_F
  U8G2_SSD1306_128X64_NONAME_F_HW_I2C u8g2(U8G2_R0);
#endif


// create dimmer instance for beeper control
DimmerZero beepCh3(BEEPER);

// create FRAM instance
//Adafruit_FRAM_I2C fram = Adafruit_FRAM_I2C();



void configRadio(uint8_t ch);
int displayPresent(uint8_t addr);
void oledMessage1(void);
void oledMessage2(void);
void oledMessage3(void);
void CH1Callback(void);
void CH2Callback(void);
void CH3Callback(void);
void RXCallback(void);
void startTimer5(int frequencyHz);
void beep(uint16_t duration, uint16_t freq, uint16_t duty);
void handleLED(uint16_t ms);
void handleDisplayUpdate2(void);
void handleDisplayUpdate3(void);
void handleRelais(void);
void handleCh1(void);
void handleCh2(void);
void handleCh3(void);
void handleRaceEvents(uint8_t eventType);

// Version
const float SWversion = 1.51;

// display buffer
char s[80];

// variables
int16_t packetnum = 0;  // packet counter, we increment per xmission
uint16_t per;
int cnt = 0;
uint16_t opMode = 0;
int txPwr = 0;
int txPwrMw = 0;
uint8_t haveFRAM = false;

// timer variables
volatile int        t_1000ms_count = TICK_COUNTS_1S;  // Counter for 1s
volatile uint16_t   pulseDetectTimer = 0;
volatile long       t_beeperCnt = 0;
volatile uint8_t    t_1000msFlag = false;
volatile uint8_t    t_1msFlag = false;
volatile uint32_t   t_EngineStartTime = 0;
volatile uint16_t   t_engineOffTimer1 = 0;
volatile uint16_t   t_engineOffTimer2 = 0;
volatile uint16_t   pwmFrequency = 0;


typedef struct {
  union {
    struct {
      byte ch1in : 1;
      byte ch2in : 1;
      byte ch3in : 1;
      byte b4 : 1;
      byte b5 : 1;
      byte b6 : 1;
      byte b7 : 1;
      byte b8 : 1;
    } chInbits;
    byte chInbyte;
  };
} crossing;

volatile crossing inStates;
volatile crossing recStates;
volatile uint8_t  legCount = 0;
volatile uint8_t  onCount = 0;
uint8_t           lastLegUpdate = 0;
volatile uint32_t pulseDuration = 0;
volatile uint32_t pulseStart = 0;
volatile uint32_t roundtripCounter = 0;
//volatile uint32_t roundtripEndBeep = 0;
uint8_t engineReportedOn = false;

uint32_t  rangeTestTimeCnt = 0;
uint8_t   motorOffBeep = false;

uint16_t ledTime = 0;
uint16_t beepTime = 0;
uint16_t relaisTime = 0;
uint16_t ch1Time = 0;
uint16_t ch2Time = 0;
uint16_t ch3Time = 0;
volatile uint8_t engineState = INV;
uint8_t ledMode = false;
uint8_t Ch3inReleased = true;
uint8_t rangeTest = false;
uint8_t rRangeTest = false;
uint32_t rRangeTestTime = 0;
volatile uint8_t startSequence = 0;
uint16_t beepDebounce = 0;

uint8_t txBuf [RH_RF69_MAX_MESSAGE_LEN];
uint8_t recBuf[RH_RF69_MAX_MESSAGE_LEN];
uint8_t txNo = 0;
uint8_t rxNo = 0xff;
uint8_t len = sizeof(recBuf);
uint8_t txBufPtr = 0;
uint8_t freqChannel;
float radioFreq;

uint8_t tmOut = false;
uint8_t waitForFullBuffer = false;
uint8_t vmea = false;
uint8_t toggle = 0;
uint8_t oledFound = false;
uint8_t updateDisplay = true;
float batteryVoltage = 0.0;
volatile uint32_t  lastBeep = 0;


// frequency channel table
const float channelTable[] = {
  000.000,  // 0 not usable
  433.150,  // 1  10mW            module with red dot!
  433.350,  // 2  10mW
  433.550,  // 3  10mW
  433.750,  // 4  10mW
  433.950,  // 5  10mW
  434.150,  // 6  10mW
  434.350,  // 7  10mW
  434.550,  // 8  10mW
  865.100,  // 9  1% duty, 25mW   module with green dot!
  865.300,  // 10 1% duty, 25mW
  865.500,  // 11 1% duty, 25mW
  865.700,  // 12 1% duty, 25mW
  865.900,  // 13 1% duty, 25mW
  866.100,  // 14 1% duty, 25mW
  866.300,  // 15 1% duty, 25mW
  866.500,  // 16 1% duty, 25mW
  866.700,  // 17 1% duty, 25mW
  866.900,  // 18 1% duty, 25mW
  867.100,  // 19 1% duty, 25mW
  867.300,  // 20 1% duty, 25mW
  867.500,  // 21 1% duty, 25mW
  867.700,  // 22 1% duty, 25mW
  867.900,  // 23 1% duty, 25mW
  868.100,  // 24 1% duty, 25mW
  868.300,  // 25 1% duty, 25mW
  868.500,  // 26 1% duty, 25mW
  868.800,  // 27 0.1% duty, 25mW
  869.000,  // 28 0.1% duty, 25mW
  869.525,  // 29 10% duty 500mW
  869.850,   // 30 1% duty, 25mW
  918.100,   // 31                 
  918.300,   // 32                  
  918.500,   // 33                  
  918.700,   // 34                  
  918.900,   // 35                  
  919.100,   // 36                  
  919.300,   // 37                  
  919.500,   // 38                  
  919.700,   // 39                  
  919.900,   // 40                  
  920.100,   // 41                  
  920.300,   // 42                  
  920.500,   // 43                  
  920.700,   // 44                  
  920.900,   // 45                  
  921.100,   // 46                  
  921.300,   // 47                  
  921.500,   // 48                  
  921.700,   // 49                  
  921.900    // 50                  
};

// The radio encryption key has to be the same as the one on transmitter and receiver!
uint8_t key[] = { 0xFE, 0x02, 0xFC, 0x04, 0xEE, 0x06, 0xEC, 0x08,
                  0x81, 0x92, 0xA3, 0xB4, 0xC5, 0xD6, 0xE7, 0xF8};
                  
// The radio sync word                  
uint8_t sync[] = { 0x2a, 0x54 };  // network, defaults to { 0x2d, 0xd4 }

// conversion of dBm to mW
uint8_t pwrTable[] = {
  10,   // 10dBm
  12,   // 11dBm
  16,   // 12dBm
  20,   // 13dBm
  25,   // 14dBm
  31,   // 15dBm
  40,   // 16dBm
  50,   // 17dBm
  63,   // 18dBm
  79,   // 19dBm
  100   // 20dBm
};


float fUtcTime = 0.0;
int32_t iUtcDate = 0;
char  pst32Status = ' ';
char  pst32Mode = ' ';
uint8_t chk;

uint8_t msgBuf[BUFLEN];
uint8_t rtcmBuf[BUFLEN];
uint16_t msgBufIndex = 0;
uint16_t rtcmBufIndex = 0;
uint16_t msgLength = 0;
uint16_t rtcmLength = 0;
uint8_t msgCheckSum = 0;
String inString = "";
String sUtcTime = "";
String sUtcDate = "";

static const byte hextable[] = { 
    255,255,255,255,255,255,255,255,255,255,255,255,255,255,255,255,255,255,255,255,255,255,255,
    255,255,255,255,255,255,255,255,255,255,255,255,255,255,255,255,255,255,255,255,255,255,255,
    255,255, 0,1,2,3,4,5,6,7,8,9,255,255,255,255,255,255,255,10,11,12,13,14,15,255,
    255,255,255,255,255,255,255,255,255,255,255,255,255,255,255,255,255,255,255,255,255,255,255,
    255,255,10,11,12,13,14,15,255,255,255,255,255,255,255,255,255,255,255,255,255,255,255,
    255,255,255,255,255,255,255,255,255,255,255,255,255,255,255,255,255,255,255,255,255,255,255,
    255,255,255,255,255,255,255,255,255,255,255,255,255,255,255,255,255,255,255,255,255,255,255,
    255,255,255,255,255,255,255,255,255,255,255,255,255,255,255,255,255,255,255,255,255,255,255,
    255,255,255,255,255,255,255,255,255,255,255,255,255,255,255,255,255,255,255,255,255,255,255,
    255,255,255,255,255,255,255,255,255,255,255,255,255,255,255,255,255,255,255,255,255,255,255,
    255,255,255,255,255,255,255,255,255,255,255,255,255,255,255,255,255,255,255,255,255,255,255
};


void CH1Callback(void) {
    // sw debounce
    shortDebounceDelay();
    if (digitalRead(CH1IN)) {
      inStates.chInbits.ch1in = 1;   // indicate channel 1 input signal interrupt
    if (opMode == 1) {    // all Rx modes
      handleRelais();
      handleCh1();
      inStates.chInbits.ch1in = 0;
      handleRaceEvents(1);  // got A signal
    }
  }
}
void CH2Callback(void){
  // sw debounce
  shortDebounceDelay();
  if (digitalRead(CH2IN)) {
    inStates.chInbits.ch2in = 1;   // indicate channel 2 input signal interrupt
  }
}
void CH3Callback(void){
  // sw debounce
  shortDebounceDelay();
  if (digitalRead(CH3IN)) {
    inStates.chInbits.ch3in = 1;   // indicate channel 3 input signal interrupt
  }
}

void RXCallback(void){
  if (opMode == 1) {    // all RX modes
    if (digitalRead(CTRLRECEIVER)) {
      pulseStart = micros();
      pulseDetectTimer = 150;   // ms
    }
    else {
      pulseDuration = micros() - pulseStart;
      if ((pulseDuration < 1350) && (pulseDuration > 995)) {
        // on/off filter (delay of one receiver servo cycle)
        if (onCount)
          onCount--;
        if ((engineState == 2) && (!onCount)) {
          engineState = 1;     // engine stopped
          t_engineOffTimer1 = 0;
          t_engineOffTimer2 = 0;
          t_EngineStartTime = 0;
        }
      }
      else {
        if ((pulseDuration >= 1350) && (pulseDuration < 3000)) {
          if (onCount < 2)
            onCount++;
          if ((engineState == 1) && (onCount == 2)) {
            engineState = 2;
            t_EngineStartTime = (millis());
            if ((opMode == 1) && (motorOffBeep)) {
              t_engineOffTimer1 = CLIMB4LEGTIME;
              t_engineOffTimer2 = CLIMB6LEGTIME;
            }
            handleRaceEvents(3);  // got motor ON signal
          }
        }
        else {
          // ignore
        }
      }
    }
  }
  else
  { // Tx modes
    // use RX channel as an alternative channel 1 input, so FCD can supply UFP2
    inStates.chInbits.ch1in = 1;    // indicate ch 1 interrupt
  }
}

void KEYRCallback(void){
  
}

// signal timing methods

// duration: 2..2000
// freq:     500..6000
// duty:     0..50      (volume 0..100%)

void beep(uint16_t duration, uint16_t freq, uint16_t duty) {
  beepCh3.setValue(0);  // stop current beep
  if (duration < 2) duration = 2;
  if (duration > 2000) duration = 2000;
  if (freq < 1000) freq = 500;
  else if (freq < 2000) freq = 1000;
  else if (freq < 6000) freq = 2000;
  if (duty > 50) duty = 50;
  beepTime = duration;
  if (pwmFrequency != freq){
//    pwm12Init(freq);
    beepCh3.setFrequency(freq);
    beepCh3.init();
    pwmFrequency = freq;
  }
  if (duty < 5)
    beepCh3.setValue(0);
  else if (duty < 25)
    beepCh3.setValue(1000);
  else
    beepCh3.setValue(2047);
  //pwm12SetDuty(duty);
}

void handleLED(uint16_t ms) {
  if (ms < 2) ms = 2;
  digitalWrite(LED,HIGH);
  ledTime = ms;
}

void handleRelais(void) {
  if (vmea)
    digitalWrite(RELAISMOD, HIGH);
  else
    digitalWrite(RELAIS, HIGH);
  relaisTime = SIGNALTIME;
}

void handleCh1(void) {
  digitalWrite(CH1OUT, HIGH);
  ch1Time = SIGNALTIME;
}

void handleCh2(void) {
  digitalWrite(CH2OUT, HIGH);
  ch2Time = SIGNALTIME;
}

void handleCh3(void) {
  digitalWrite(CH3OUT, HIGH);
  ch3Time = SIGNALTIME;
}
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
void loop() {
  if (true) {
    if (opMode == 0) {        // TX modes
      
      // check for crossing signals
      // CH3IN w/o interrupt, but on rising edge only
      if (digitalRead(CH3IN)) {
        if (Ch3inReleased) {
          inStates.chInbits.ch3in = 1;
          Ch3inReleased = false;
        }
      }
      else {
        Ch3inReleased = true;
      } 
      if (inStates.chInbyte) {
        // Send a message!
        txBuf[0] = txNo++;
        txBuf[1] = inStates.chInbyte;
        rf69.send(txBuf, RH_RF69_MESSAGE_LEN);
        // done, clear crossing flags
        inStates.chInbyte = 0;
        beep(MBEEPTIME,1000,15);
        rf69.waitPacketSent();
        // resend message once after short delay
        delay(2);
        rf69.send(txBuf, RH_RF69_MESSAGE_LEN);
        handleLED(50);
        handleDisplayUpdate3();
        rf69.waitPacketSent();
      }
    }
    else {        // all RX modes 
      // Handle received message
      if (rf69.available()) {
        len = RH_RF69_MAX_MESSAGE_LEN;
        // a message should be received
        if (rf69.recv(recBuf, &len)) {
          if (len == RH_RF69_MESSAGE_LEN) {
            if (recBuf[0] != rxNo) {
              // new message received, not just a copy
              rxNo = recBuf[0];
              if (recBuf[1] >= 128) {
                rRangeTest = true;
                rRangeTestTime = millis();
              }
              else
                rRangeTest = false;
              recBuf[1] = recBuf[1] & 0x7F;
              recStates.chInbyte = recBuf[1];
              if (recStates.chInbyte)
                handleRelais();
              if (recStates.chInbits.ch1in) 
                handleCh1();
              if (recStates.chInbits.ch2in)
                handleCh2();
              if (recStates.chInbits.ch3in)
                handleCh3();
              recStates.chInbyte = 0;
              handleRaceEvents(2); // got B signal
              handleLED(100);
            }
            else {
              ;
              //Serial.println("Backup message dropped.");
            }
          }
          else {
#ifdef debug
            Serial.println("Invalid message length");
#endif
          }
        } else {
#ifdef debug
          Serial.println("Receive failed");
#endif
        }
      }
      
      //
      // check for local commands (typically at A-Base)
      //
      if (digitalRead(CH3IN)) {    // start signal on channel 3 at A-Base
        if (Ch3inReleased) {
          Ch3inReleased = false;
          handleRaceEvents(0);    // got Start signal
        }
      }
      else {
        Ch3inReleased = true;
      }
      // clear crossing flags
      inStates.chInbyte = 0;
    }
  }

  
  //
  // general tasks in main loop
  //

  // life sign, blink LED
  if (t_1000msFlag) {
    t_1000msFlag = false;
    // Range Test
    if (rangeTest) {
      txBuf[0] = txNo++;
      txBuf[1] = 0x83;  // msb set
      rf69.send(txBuf, RH_RF69_MESSAGE_LEN);
      rf69.waitPacketSent();
      beep(MBEEPTIME,1000,15);
      handleLED(100);
    } else {
      handleLED(10);
      if (vmea)
        batteryVoltage = analogRead(A7) * 6.6 / 1024;
    }
    if (!updateDisplay) {
      if (millis() >= lastBeep + 20000) {   // reactivate background update of display after 20s of inactivity
          updateDisplay = true;
      }
    }
    // check for range test request; off only by reset!
    if (opMode == 0) {        // TX modes
      if (digitalRead(CH3IN)) {
        if ((millis() - rangeTestTimeCnt) > 5000) {
          // range test requested
          rangeTest = true;
        }
      }
      else {
        rangeTestTimeCnt = millis();
      }
    }
    // Update OLED display
    if (opMode == 1) {   // Rx modes
      if (updateDisplay)
        oledMessage2();
      pulseDuration = 0;
    }
    else {               // Tx modes
      if (vmea)
        if (updateDisplay)
          oledMessage3();
    }
  }
} //*** End of Main *********************************************************//

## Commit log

2026-05-21 Add UFP2 enclosure STL files
    [UFP2_1_V7_case_bottom.stl, UFP2_2_V4_case_main.stl, UFP2_3_V8_case_top.stl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]
2026-05-24 Add UFP2 production PCB files
    [UFP2.GBL, UFP2.GBO, UFP2.GBP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]
